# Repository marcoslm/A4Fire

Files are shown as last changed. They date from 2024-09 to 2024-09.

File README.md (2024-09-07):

# A4Fire - Circuito de Auto-disparo

Este proyecto fue desarrollado en 2015 para cumplir con los requerimientos específicos de **Enrique García** para su proyecto personal. El código es sencillo y el circuito es fácil de construir para cualquier aficionado a la electrónica.

## Descripción del Proyecto

El firmware implementa un circuito de auto-disparo para joysticks y gamepads compatibles con las normas **Atari/Commodore**, y es compatible con otros sistemas como **MSX** o **Amstrad CPC**. Está diseñado para funcionar con un microcontrolador **PIC 10F200** y fue creado usando el entorno de desarrollo **MPLAB X v2.05** con el compilador **XC8**.

A4Fire fue desarrollado como parte del proyecto del joystick A4 de Enrique García. Puedes encontrar más información sobre su proyecto en su [canal de YouTube](https://www.youtube.com/channel/UCb7_NkehBK6dyK2aAPUDlYA).

## Estructura del Proyecto

El proyecto está organizado en dos secciones principales:

1. **Circuito**: Contiene los archivos necesarios para el diseño del circuito y la placa PCB.
   - Archivos de diseño en Eagle.
   - Esquema y detalles de las conexiones.
   - Archivos PDF con las vistas previas del diseño (`Bottom.pdf` es la cara de las pistas y `TopSilk.pdf` es la serigrafía). Los archivos están listos para imprimir a escala real y fabricar el circuito de manera casera.

2. **Firmware**: Incluye el código fuente y el archivo compilado (.hex) listo para ser grabado en el microcontrolador PIC.
   - `main.c`: Código fuente del firmware.
   - `A4-autofire-PIC10F200.hex`: Archivo compilado para grabar en el PIC 10F200.

## Instrucciones

1. Utiliza los archivos PDF para fabricar la placa de circuito de forma casera. El archivo `Bottom.pdf` contiene la vista de las pistas, y el archivo `TopSilk.pdf` es la serigrafía para imprimir a escala real.
   
2. El archivo `A4-autofire-PIC10F200.hex` se puede flashear en un microcontrolador **PIC 10F200** usando cualquier programador compatible o universal, como los populares programadores de la serie **TL866**.

Circuito
IMAG2732

## Esquema de Conexiones

| SERIGRAFÍA | NOMBRE | DESCRIPCIÓN |
|---|---|---|
| FO | FIRE OUT | Salida de disparo hacia el ordenador |
| G | GROUND | Tierra |
| +5 | +5 VOLTS | Alimentación a 5V (desde el conector o batería) |
| FI | FIRE IN | Botón de disparo (botón físico del joystick) |
| SW1 | SWITCH | Interruptor para activar/desactivar autofire |
| SPEED | SPEED SEL | Selección de velocidad (1-2 = Normal, 2-3 = Turbo) 

## Licencia

Este proyecto está licenciado bajo la licencia MIT. Eres libre de usar, modificar y distribuir el proyecto tanto para fines personales como comerciales. Además, puedes sublicenciar y/o vender copias del proyecto. Consulta el archivo [LICENSE](./LICENSE) para más detalles.

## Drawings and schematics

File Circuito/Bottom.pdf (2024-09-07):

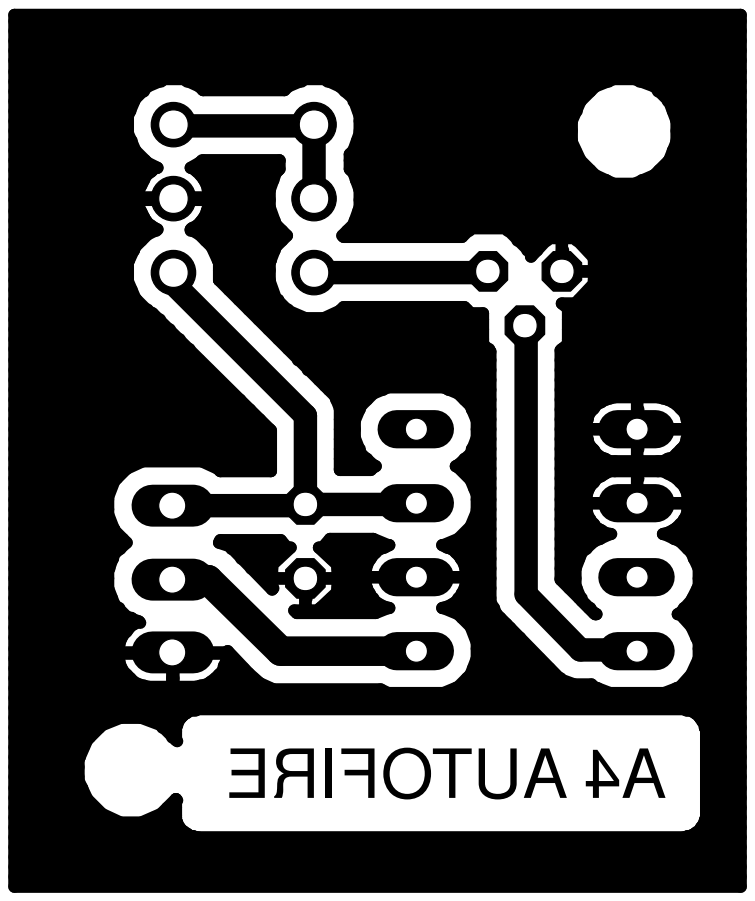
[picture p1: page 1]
A4 AUTOFIRE

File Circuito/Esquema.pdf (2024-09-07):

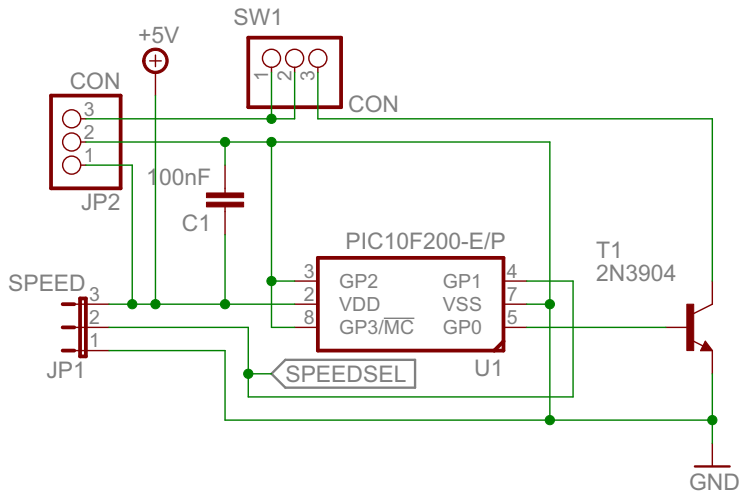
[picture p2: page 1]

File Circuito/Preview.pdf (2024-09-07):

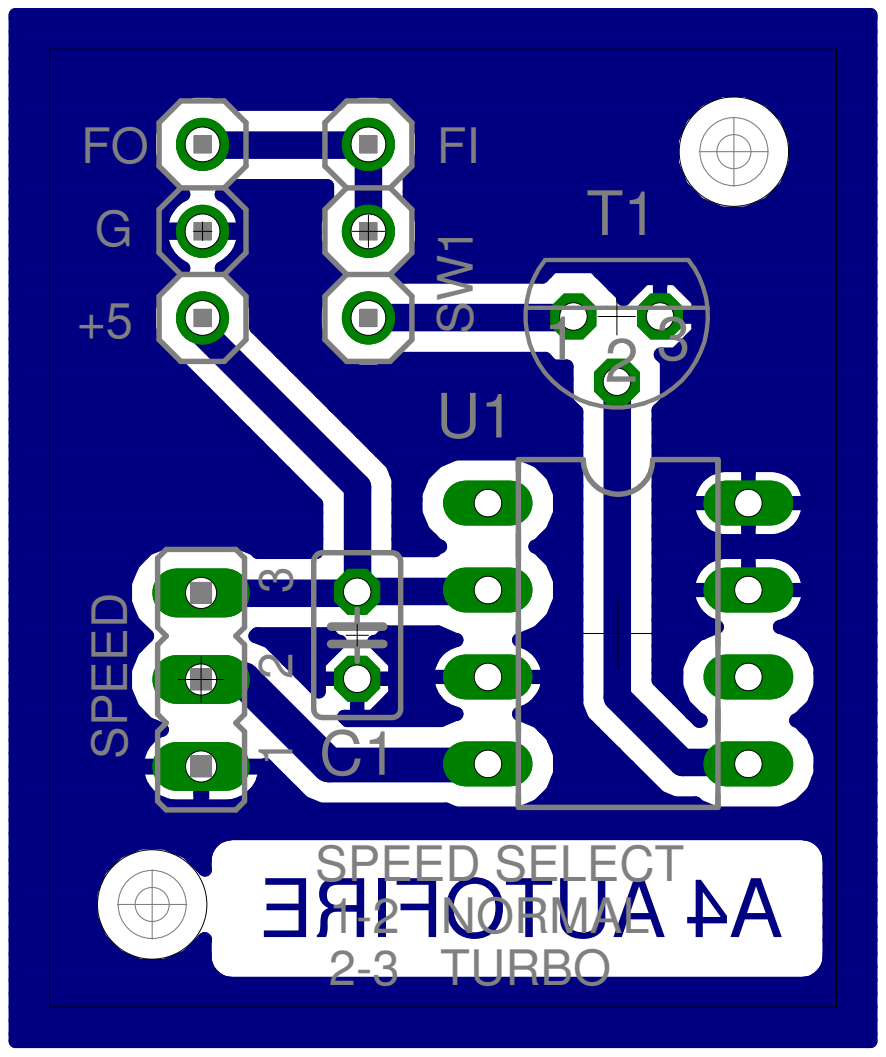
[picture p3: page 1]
SPEED SELECT 1-2 NORMAL 2-3 TURBO; SPEED

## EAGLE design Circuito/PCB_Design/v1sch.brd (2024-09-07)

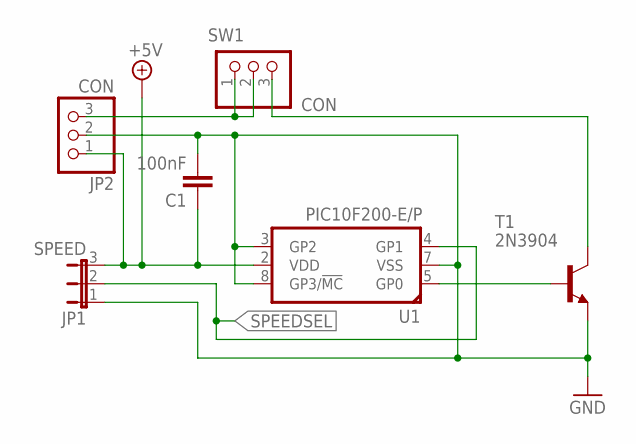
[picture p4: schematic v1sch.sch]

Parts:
C1: 100nF; C025-025X050
JP1: SPEED; JP2
JP2: CON; 1X03
SW1: CON; 1X03
T1: 2N3904; TO92; MPN 2N3904
U1: PIC10F200-E/P; DIL08

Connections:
+5V: C1.1, JP1.3, JP2.1, U1.2 (VDD)
GND: C1.2, JP1.1, JP2.2, T1.3 (E), U1.3 (GP2), U1.7 (VSS), U1.8 (GP3/!MC!)
unnamed: SW1.3, T1.1 (C)
unnamed: JP2.3, SW1.1, SW1.2
unnamed: T1.2 (B), U1.5 (GP0)
SPEEDSEL: JP1.2, U1.4 (GP1)

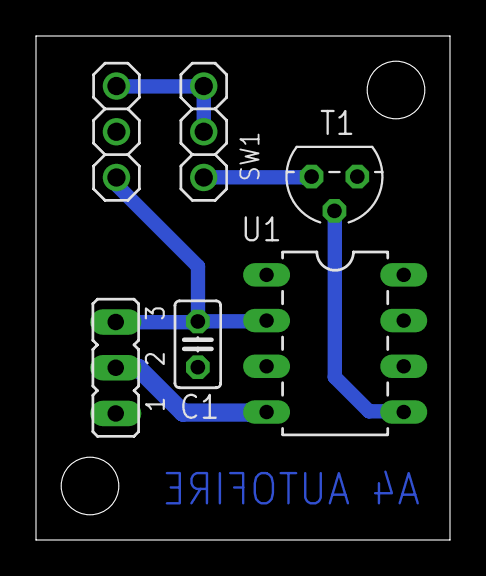
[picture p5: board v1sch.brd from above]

Board: 2 copper layers, 23.0 x 28.0 mm, 6 parts (0 on the bottom side), 6 nets.

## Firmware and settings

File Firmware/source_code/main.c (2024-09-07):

/* 
 * File:   main.c
 * Author: Marcos López Merayo
 *
 * Firmware sencila que implementa un circuito de auto-disparo para joysticks y
 * gamepads compatible con las normas Atari/Commodore (adaptable a MSX, Amstrad,
 * etc).
 * Versión específica para el proyecto A4 de Enrique García. Más info sobre el
 * proyecto en su canal de YouTube: 
 * https://www.youtube.com/channel/UCb7_NkehBK6dyK2aAPUDlYA
 *
 * Este programa se ha escrito para el microcontrolador PIC 10F200
 * IDE: MPLAB X v2.05
 * Compilador: XC8
 * 
 * Created on 29 de mayo de 2015, 23:23
 */

#include <stdio.h>
#include <stdlib.h>
#include <GenericTypeDefs.h>
#include <xc.h>

// Bits de configuración del PIC
// CONFIG
#pragma config WDTE = OFF       // Watchdog Timer (WDT disabled)
#pragma config CP = OFF         // Code Protect (Code protection off)
#pragma config MCLRE = OFF      // Master Clear Enable (GP3/MCLR pin fuction is digital I/O, MCLR internally tied to VDD)

#define __XTAL_FREQ 4000000     // 4MHz
#define FIRE    GPIObits.GP0    // Puerto para la salida de auto-disparo
#define SPEED   GPIObits.GP1    // Jumper selección de velocidad (normal/turbo)
#define P2      GPIObits.GP2
#define P3      GPIObits.GP3
#define HISPEED 42              // 12 disparos/s (turbo)
#define LOSPEED 63              // 8 disparos/s  (normal)

void delay_ms(long milisecs);
int MS;

/*
 * Bucle principal
 */
int main(void) {

    TRIS = 0b11111110;    // Todos los puertos como entrada excepto GP0 (salida Auto-FIRE)
    FIRE = 0;

    while(TRUE){
        delay_ms(MS);    
        FIRE = 1;
        if (SPEED==1){
            MS = HISPEED;   // Velocidad Turbo
        }
        delay_ms(MS);
        FIRE = 0;
        if (SPEED==0){
            MS = LOSPEED;   // Velocidad Normal
        }
    }

    
}


// Función para realizar retardos en milisegundos
void delay_ms(long milisecs){
    while (milisecs > 0) {
        _delay(1000);   // 1ms con reloj de 4MHz
        milisecs--;     // restamos 1 del contador
    }
}
